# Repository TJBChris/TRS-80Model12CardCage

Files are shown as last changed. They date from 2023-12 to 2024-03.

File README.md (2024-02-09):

# TRS-80 Model 12 Card Cage

**Check out the tandy_emeritus folder Tandy Emeritus-provided resources related to their expansion backplane.**  You can find the TE-designed insulator, which is needed when using their backplane with the original metal Tandy card cage chassis, in this folder.

## About
This is a card cage chassis replacement for the TRS-80 Model 12 business microcomputer.  The Model 12 did not include the seven-slot card cage by default; it was available as an add-on.  Its bigger borthers (the TRS-80 Model 16B and later the Tandy 6000) include this cage.  This project should also be usable in those machines should you find yourself with a pillaged system.  Naturally, you'll need a seven-slot backplane in order for this to be useful.

Please note this is only the second thing I've ever "made".  It's also the first multi-part "thing" I've made.  I'm still learning and am very new at this.  It shows.  Even so, this is a crude-but-servicable item.  As such, you should expect that things aren't perfect and I may not be able to fix issues as quickly as a more-experienced person.  For example, screw holes may not align perfectly, or you may find other issues.  But, in the spirit of open source, if you find areas you'd like to improve and have more experience than I, feel free to fork the project, make your improvements, and submit a Pull Request back to me.  I'd be happy to incorporate any fixes you may have.

This project assumes a basic familiarity with 3D printing and working with computers of the Model 12's vintage. This documentation is written from that perspective.  If you're new to 3D printing, I'd suggest any one of the plethora of Hello World-style tutorials that are available on the web.

My YouTube videos for this project can be found here: https://youtube.com/playlist?list=PLNLZVk0TSZFJRB-gEgNvk96HBEzzWrhk3&si=kmpUlS4L6hQPK3qs

The videos also contains some detail on the caveats below.

## Differences from Tandy's Cage

This cage is different from the Tandy design in the following ways:

* It is missing the **card stop** that stops one from inserting a card into the slot at an angle.
* It lacks the **screw-on braces** which attach at the rear of the cages to hold the cards in place.
* The top does not have the **rear overhang** which meets with the backplane.
* It's not metal (and thus won't help you in the RFI department, and it creates some additional considerations around grounding).

## Making and Using the Cage

If you don't have your own 3D printer, yours isn't large enough, or you just don't want to babysit your printer for about three days, you can have one of many 3D printing houses print the cage for you.  I've personally used these two with success:

* ShapeWays - https://www.shapeways.com/
	* Material: PA12 (SLS) [Versatile Plastic]
	* Color: Black (Shapeways only allowed black or white for these parts.)
	* Finish: Natural
	* I let Shapeways determine infill and such.  

* CraftCloud - https://craftcloud3d.com/
	* Material: PLA (FDM)
	* Color: Black 
	* Finish: Standard
	* I let CraftCloud determine infill and such.  	

It will probably be fairly pricey to get all three parts printed.  A plastic material with some tolerance for temperature variations would be preferable.  

If you're printing it yourself, check out the **doc/cage** folder for instructions building the cage, along with the required materials and tools.

## Caveats And Considerations

Please note the following considerations:

* **Grounding** You will need to provide grounding for the keyboard and video connectors.  The Tandy cage is metal, and contains spade connectors onto which you can attached the grounding leads.  You'll need to provide a way to ground these connectors.  Additionally, there are a couple of chassis ground leads that you'll need to make sure are attached as you install the card cage into your Model 12.
* **Heat** For a setup with a one-three cards, the existing fan should suffice.  It's worth noting the Tandy card cage design did not allow for proper heat dissipation in the Models 12 and 16B; as a result, a modification often referred to as the **Turbo Fan Mod** became popular.  This was accomplished by cutting a large hole into the back cover of the system and attaching a 120V fan to the cover.  The fan was then wired to the AC line voltage at a terminal block by the power supply.  The system can easily overheat if you don't mitigate heat issues.  If you're planning to load up the expansion slots with cards, you should strongly consider doing the Turbo Fan Mod.  There is a 3D-printable rear panel replacement on Thingiverse (not my project).  It has space for two fans.  See: https://www.thingiverse.com/thing:5172782
* **Fit** Variataions in your printer, material, and the demensions of the system chassis and backplane may lead to situations where parts don't quite align perfectly.  As an example, the backplane in my Model 12 has a slight curve to it, and the metal chassis in the system is not perfectly straight.  I've tried to take this into account, but you may need to finagle things a bit or adjust hole sizes to fit your paritcular system.  Similarly, the chassis in my 12 was bent slightly outward in such a way that things didin't fit quite right.  My 16B, which has a factory-installed card cage, looked as though the chassis had been bent to fit the cage.  You may have to...adjust...things a bit for a best fit.  This is a situation where manufacturing variations may come into play...
* **Power** Your Model 12 may not have the additional harness needed to power the card cage.  My Model 12 is one of these systems.  As a result, you'll need to find a way to get +12, -12, and 5V to the cage along with their grounds.

## License / Copyright

 TRS-80 Model 12 Card Cage © 2023 by TJBChris (Christopher Hyzer) is licensed under CC BY-NC-SA 4.0

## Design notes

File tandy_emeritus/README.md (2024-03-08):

# Tandy Emeritus - Related Items

## About
This page contains items created by Tandy Emeritus in support of their Model 12/16B/6000 backplane.  See the descriptions below for each item here.  I didn't create these items, but it made sense to host them here as part of the larger Model 12 expansion project. 

Please see backplane documentation, **Backplane-Instructions-Rev_B1.pdf**, for complete information on all of the TE components here as well as the backplane itself.  If you have any questions about any of these items, the documentation contains contact information.

## Items

These are the TE-provided items I have here for the card cage project:

* **Backplane-Instructions-Rev_B1.pdf** - Complete assembly instructions and technical documentation for the TE Backplane, Test Fixture, and Diagnostic Spacer.
* **BackPlane_Covers_RibbonClip_STLs.zip** - Insulative parts and clips for use with the new Tandy Emeritus backplane to prevent shorts and help with cable management.  There are three parts in the ZIP file:

  **TE-Cage-Insulator.stl** - For use when the TE backplane is paired with the original Tandy metal card cage assembly.  Prevents contact between the card cage top and **This part is not necessary for the 3D-printed card cage in this repository.**  

  **TestFixture-ribbons-clip.stl** - Allows you to clip together the ribbon cables used to extend the system bus from the backplane's connectors out to the Test Fixture assembly.

  **BP_Power-IDE_Cover_V1.stl** - The new backplane has components in places that the legacy Tandy backplane did not.  This part prevents the solder joints for the dual 40-pin bus expansion headers and the power connector from contacting the metal chassis behind the backplane. 
  
* **External_Test_Fixture_STLs.zip** - Contains all of the parts necessary to build a housing for the TE Test Fixture board.  Also contains the cable ribbon clips found in BackPlane_Covers_RibbonClip_STLs.zip.

## Notes

* All of the STLs that use screws/nuts use M3.  Be sure to use metal screws/nuts.

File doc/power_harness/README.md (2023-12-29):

# Building the power harness

The power harness should supply ample power for a couple of cards (2-3) in the cage.  As of this writing, more cards haven't been tested.  For a full compliment of cards, you may want to re-work the entire system harness.  Doing so is beyond the scope of this document.

## Tools
The following tools are recommended (beyond a 3D printer and filament, of course):

* A TE crimper or another way to crimp TE pins.
* A soldering iron.
* Solder.
* Heat shrink tubing (approx. 1.9cm and 1.3 diameter).

## Materials
The following materials are required:

### Ground Connectors
Use high-quality spade connectors.  For best results, choose insulated female connectors.  
* Female terminal connectors (.635cm/.25")
* Male flat terminals (.635cm/.25")

### TE Connectors
The materials required for the power and grounding build are as follows.  You can find them on **DigiKey**.

* Male connector housing: 1-480271-0
* Female connector housig: 1-480270-0
* Female pins: 350550-1
* Male pins: 1062-16-1422

### Tools

The following tools/die sets are recommended.  While you can crimp these connectors without the TE tools, it may prove difficult.

* TE Crimper: 354940-1
* Pinned Die Set: 90546-2

### Wire

It's recommended that you use colored wire in the correct gauge (noted below).  This will greatly lessen confusion.  The recommended colors are noted along with the wire.  **IMPORTANT**: Note that the 5v (red) wire is larger than the remaining conductors.

You'll need the following wire, in the color, gauge and length noted:

* Red: 14 AWG stranded wire.  You'll need 30cm.
* White: 16 AWG stranded wire.  You'll need 30cm.
* Orange: 16 AWG stranded wire.  You'll need 30cm.
* Black: 16 AWG stranded wire.  You'll need 90cm (you're making three sets of cables).

## Assembling the power cable

To assemble the splitter, do the following:

1. Cut the red, white, and orange wire into three sections: One **10cm** length, and two **20cm** lengths.  Group the wires together by color.  For each color, you should have one 10cm length of wire and one 20cm length of wire.
1. Cut the black wire into nine sections: three **10cm** sections, and six **20cm** sections.  Group the black wire into three groups of one 10cm wire and two 20cm wires.
1. For each group of wires, strip off about **2-3cm** of the jacket and twist the strands.
1. For each group of wires, splice together one end of the **10cm** section to one end of each of the remaining two **20cm** sections.
1. Solder the spliced connection.
1. Slide the heat shrink tubing over each section (using the larger diameter tubing for the 14 AWG wire set.)
1. Shrink the tubing with a heat gun or lighter.
1. For each group of wires, crimp a male TE connector to the short lead.
1. Solder the wires to the pins.
1. For each group of wires, crimp female TE connectors to each of the longer leads.
1. Solder the wires to the pins.
1. Using the Model 12 motherboard power harness as a guide, insert the crimped ends into the connector housings.

## Assembling the ground harness

You'll need to reproduce the grounding available with the Tandy cage.  You'll need:

* Approximately **15-20cm** of 16 AWG stranded wire.
* One female terminal connector (.635cm/.25")
* Three male flat terminals (.635cm/.25")

To assemble the harness:

1. Cut the wire into four sections, each approximately **5cm**.
1. Strip about **2-3cm** of the jacket off of each end of each wire.
1. Splice one end of each of the four pieces of wire together.
1. Solder the connection on all sides.
1. Slide heat shrink tubing over the soldered joint.
1. Using a heat gun or lighter, shrink the tubing.
1. Crimp the connectors onto each of the stripped ends.

The female terminal of the ground harness is intended to be attached to the ground spade on the right side of the card cage, where the CRT ground normally attaches.  Attach the CRT, keyboard, and video driver grounds to the male ends.  **Wrap the connected grounds with electrical tape.**

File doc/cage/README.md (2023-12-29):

# Building the card cage

You'll need to print each of the three STL files here.  Each of the sides has its own STL file.  You'll need a printer with printable volume of at least 256x256x256.  I've successfully used the **Anycubic Kobra Plus** printer, as well as the **Bamnu Labs X1 Carbon**.  The following YouTube video documents the assembly in detail: https://youtu.be/dfIf2Al25_E.  The assembly section begins at 22:23.

## Tools
The following tools are recommended (beyond a 3D printer and filament, of course):

* A flat-head screw driver
* A philips head screw driver
* Clamps
* Wire strippers (14 and 16 AWG).

## Materials
The following materials are required:

* A seven-slot backplane for your TRS-80 Model 12.
* PLA or the material of your choice.  I've used PLA thus far with success.  I'm using: SUNLU 3D Printer Filament PLA, PLA Filament 1.75mm, Black PLA, Polylactic Acid.  You can find it on Amazon here: https://a.co/d/hkB7bHi
* PCB board guides (14 total; 7 per side).  I used DigiKey P/N **36-8623-ND** (made by Keystone Electronics, part #8623).  The guide holes in the cage are spaced for these particular guides.  This link was valid as of this writing: https://www.digikey.com/en/products/detail/keystone-electronics/8623/317060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
* M3 screws and matching nuts to attach the cage to the backplane.  The screw holes in these parts are sized with the major diameter of M3 screws in mind.  I used this 280-piece set from Amazon: https://a.co/d/1WeQXiK
* Optionally, threadlock to secure the screws and nuts.
* Six screws to attach the cage to the chassis of the system.  Metal is recommended here; you can re-use the screws currently holding the Model 12's existing metal housing, as you'll be removing it.

## PLA
Slice the STL files according to your material and printer and print them one-at-a-time.  I use Ultimaker Cura for this task.  The PLA I'm using is:

SUNLU 3D Printer Filament PLA, PLA Filament 1.75mm, Black PLA
You can find it on Amazon here: https://a.co/d/hkB7bHi

## Printer Settings
I use the following settings:

* Cura Profile: **Fine** (I start with this and then adjust the settings below.)
* Infill Density: 20%
* Infill pattern: triangle (grid also seems to work well)
* Print temp: My PLA has a range from 200-210 C, I print at 200 C.  Your temp will vary based on material.
* Print bed temp: 60 C (if your printer has a heated bed; will vary based on your material and bed type).
* The default orientation of the STL files should avoid the need to print supports.

If your printer is on the faster side (along the lines of the **Bambu Labs X1 Carbon**), it's recommended that your first layer speed be reduced to **30mm/s** or less.

## Post-Print Tweaks
After printing, you may find the screw holes may have material preventing you from inserting the screws; a stright pick should allow you to work the excess material out.  I routinely run the pick through each screw hole before attempting to assemble it to make life easier.  With higher quality materials and printers, this is less likely to be necessary.

## Assembly

* Snap the PCB card guides into the cage sides.  You may want to use glue or another adhesive, though I've found the DigiKey guides noted above snap in and reimain in place without glue.
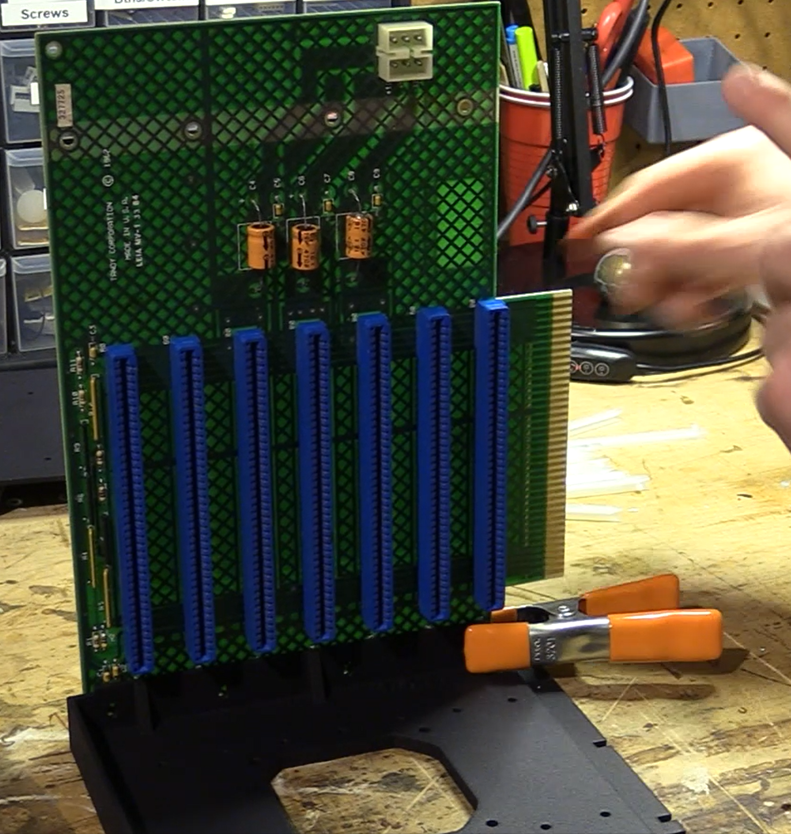
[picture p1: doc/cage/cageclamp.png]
Clamping the cage to the plane.
* Attach the sides to your backplane using M3 screws and nuts.  Use clamps to hold the backplane to the cage while you thread the first couple of screws in each side.  **Do not fully tighten the screws.**  You'll note that the screws are smaller than the holes in the cage assembly; this is intended to allow you some wiggle room to adjust in case the width is a milimeter off in any direction.  This also helps to account for any variation in printing. 
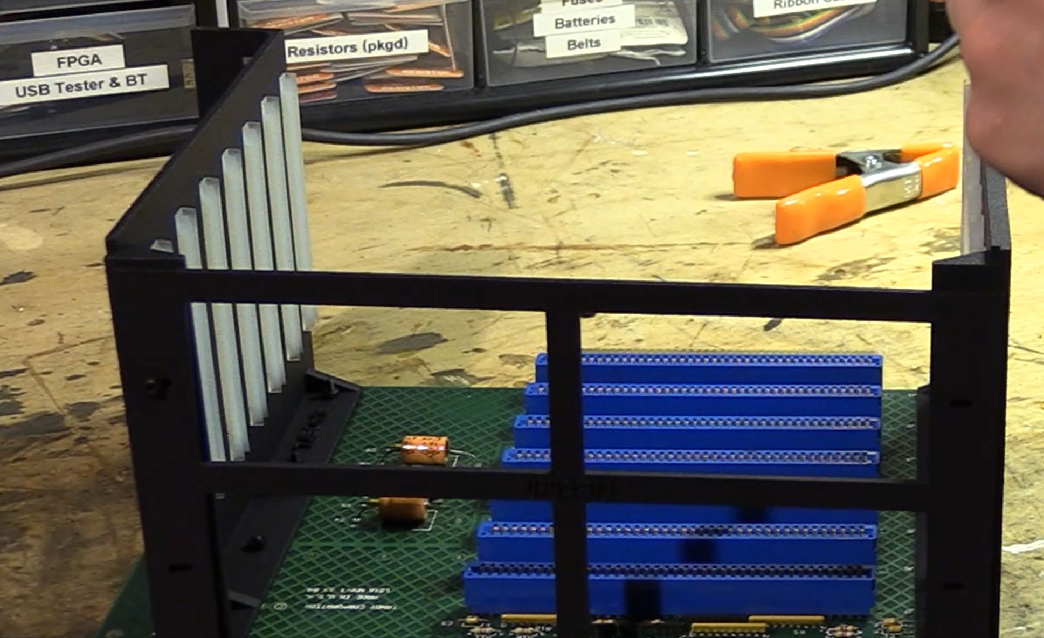
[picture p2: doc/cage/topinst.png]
Attaching the top.
* Attach the top, again with four M3 screw/nut pairs.  Again, **do not fully tighten the screws**.  
* Disassemble your Model 12, then disconnect and remove the video card from the computer.
* Test card fit by using the video card and attempting to insert it into each of the slots of the assembled card cage.  Loosen the screws/nuts where needed to adjust the alignment as-needed for best fit for all slots.  Tighten the screws when you're happy with the fit.   Video card test fit.
* Remove and disassemble the existing metal cage holding the cooling fan from your Model 12.  Set the fan aside, along with its screws/nuts.  (See **Caveats** below). 
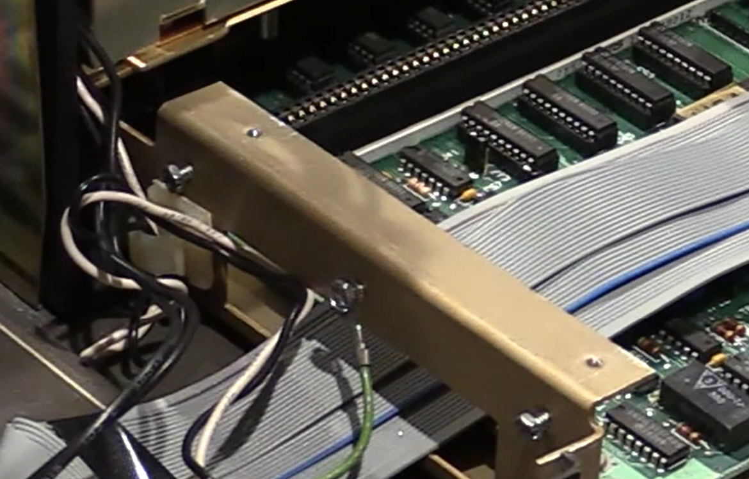
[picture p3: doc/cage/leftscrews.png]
Pre-started chassis screws.
* Start the three screws on the left-hand side of the metal chassis.  These might be hard to start, so doing this before putting the cage in place will make things easier.  **Be sure you attach the factory ground lead to the middle screw.**  Ideally, when you install the top of the cage, the ground will be nestled between the left side of the cage and the metal chassis.  
* Install your power harness adapter/splitter.  **See the doc folder.**
* Attach the printed cage to the chassis and screw it in place, ensuring any factory grounds are installed between the metal chassis and the cage sides.  Use the screws you removed from the metal cage.  **You may find the metal doesn't line up perfectly;** my 16B looks as though it had been "tweaked" (bent) a bit to fit Tandy's card cage; use the screw holes to trim out as best as you can, and don't be afraid to adjust the chassis a bit.
* Make and run your grounding solution (providing spade terminals onto which the keyboard and video ground cables can be attached).  **See the doc folder.**
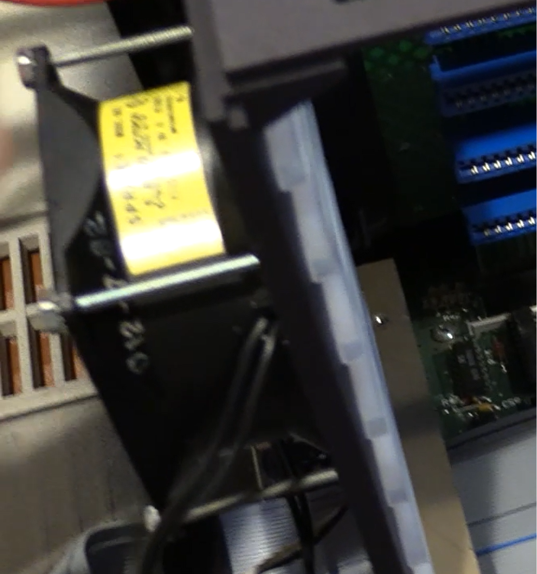
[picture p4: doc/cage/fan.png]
Fan installed
* Install the fan on the outside of the cage using the screws that you removed earlier.  Be sure the airflow is directed toward the back of the drives (so the fan pulls air through the cage, rather than pushing air into it).  
* Insert the video card and any other cards you have.
* Enjoy the feeling of running a non-neutered Model 12!

## Caveats And Considerations

Please note the following considerations, repeated from the main README:

* ****Grounding** You will need to provide grounding for the keyboard and video connectors.  The Tandy cage is metal, and contains spade connectors onto which you can attached the grounding leads.  You'll need to provide a way to ground these connectors.  Additionally, there are a couple of chassis ground leads that you'll need to make sure are attached as you install the card cage into your Model 12.  **See the doc folder for grounding instructions.**
* **Heat** For a setup with a one-three cards, the existing fan should suffice.  It's worth noting the Tandy card cage design did not allow for proper heat dissipation in the Models 12 and 16B; as a result, a modification often referred to as the **Turbo Fan Mod** became popular.  This was accomplished by cutting a large hole into the back cover of the system and attaching a 120V fan to the cover.  The fan was then wired to the AC line voltage at a terminal block by the power supply.  The system can easily overheat if you don't mitigate heat issues.  If you're planning to load up the expansion slots with cards, you should strongly consider doing the Turbo Fan Mod.  There is a 3D-printable rear panel replacement on Thingiverse (not my project).  It has space for two fans.  See: https://www.thingiverse.com/thing:5172782
* **Fit** Variataions in your printer, material, and the demensions of the system chassis and backplane may lead to situations where parts don't quite align perfectly.  As an example, the backplane in my Model 12 has a slight curve to it, and the metal chassis in the system is not perfectly straight.  I've tried to take this into account, but you may need to finagle things a bit or adjust hole sizes to fit your paritcular system.  Similarly, the chassis in my 12 was bent slightly outward in such a way that things didin't fit quite right.  My 16B, which has a factory-installed card cage, looked as though the chassis had been bent to fit the cage.  You may have to...adjust...things a bit for a best fit.  This is a situation where manufacturing variations may come into play...
* **Power** Your Model 12 may not have the additional harness needed to power the card cage.  My Model 12 is one of these systems.  As a result, you'll need to find a way to get +12, -12, and 5V to the cage along with their grounds.  **See the doc folder for materials and build instructions for the power harness.**

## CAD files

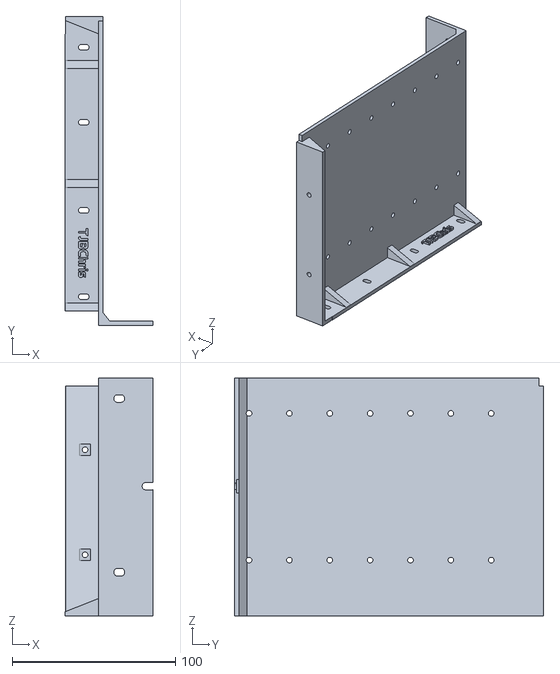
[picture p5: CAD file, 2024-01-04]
TRS-80 M12 Cage Right Side.stl
54.0 x 189.8 x 146.0

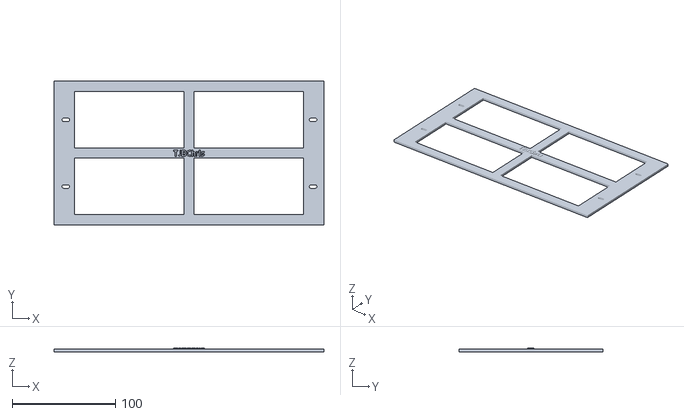
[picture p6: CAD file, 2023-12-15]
TRS-80 M12 Cage Top.stl
261.0 x 139.0 x 3.74

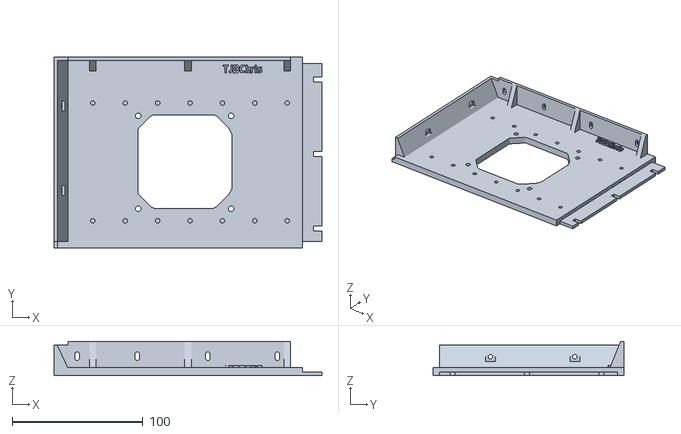
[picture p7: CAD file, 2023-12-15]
TRS-80 M12 Cage Left Side.stl
204.8 x 146.0 x 26.0

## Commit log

2023-11-24 First release revision; reinforcements and fan mount added.
    [TRS-80 M12 Cage Left Side V2.stl, TRS-80 M12 Cage Right Side V2.stl, TRS-80 M12 Cage Top V2.stl]
2023-11-25 Moved mount to avoid PCB guide conflict.
    [TRS-80 M12 Cage Left Side V2.stl]
2023-11-27 Revised fan location, enlarged top cutouts for nuts, moved RH backplane screw up .5 mm.
    [TRS-80 M12 Cage Left Side V2.stl, TRS-80 M12 Cage Right Side V2.stl, TRS-80 M12 Cage Top V2.stl]
2023-11-29 Added YouTube playlist, and removed excess from fan cutout.
    [TRS-80 M12 Cage Left Side V2.stl]
2023-12-02 Made the logo more...me.
    [TRS-80 M12 Cage Left Side V2.stl, TRS-80 M12 Cage Right Side V2.stl, TRS-80 M12 Cage Top V2.stl]
2023-12-06 Revised screw holes, PCB guide pos. on right side, PCB guide hole depth on left side.
    [TRS-80 M12 Cage Left Side V2.stl, TRS-80 M12 Cage Left Side.stl, TRS-80 M12 Cage Right Side V2.stl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]
2023-12-14 Removed small overlap between triangular supports and left side panel.
    [TRS-80 M12 Cage Left Side.stl]
2023-12-15 Removed disclaimer from readme; created notch in right side to accommodate ground spade.
    [TRS-80 M12 Cage Right Side.stl]
2023-12-29 Added initial power harness and assembly doc.
2023-12-29 Added photo for wire grouping
2023-12-29 Added CraftCloud and Shapeways detail; also added spade connector suggestions.
2024-01-03 Widened chassis screw holes on right side.
    [TRS-80 M12 Cage Right Side.stl]
2024-02-09 Added Tandy Emeritus insulator for TE backplane used with the original metal cage chassis.
    [TE-Cage-Insulator.stl]
2024-02-10 Updated TE insulator readme with 3D print settings.
2024-03-08 Added Tandy Emeritus STLs for insulator covers, test fixture, and documentation.
    [TE-Cage-Insulator.stl]
2024-03-08 Added note about M3 screws to readme.
